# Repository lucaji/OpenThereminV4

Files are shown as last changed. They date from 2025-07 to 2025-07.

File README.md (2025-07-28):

# OpenTheremin v4.x platformio IDE

a new fork for the open source Theremin instrument software and hardware project by [GaudiLabs](https://github.com/GaudiLabs/OpenThereminV4). Adapted for [platformio](https://platformio.org/) IDE. Schematics, printed circuit board (PCB) design, bill of materials (BOM) and Arduino UNO compatible software for the OpenTheremin v4.x

> This repository brings an refactored, cleaned, fully commented and slightly optimized firmware for all OpenTheremin v4.x boards.

Lots of experimentation with this firmware is possible, check `build.h` for options.

## Waveform interpolation

Three waveform interpolation algorithms are included for experimenting with the 328p DDS generation:

- NONE (LEGACY)
- LINEAR
- HERMITE
- CATMULL-ROM (pushing the limits of the 328p - computational hungry!)

There is an interactive mode where each mode can be selected by muting/unmuting the Theremin. Using the NONE (LEGACY) mode, gives anyway a clean spectrum content on the audio output, fast responsiveness and an extended pitch range because of the optimizations that were already in place in the original OpenTheremin firmware.

## Serial port configuration

- Off (saves resources!)
- DEBUG (gives some state information)
- MIDI (emits MIDI data at 31250bps)

## Open Source Theremin based on the Arduino Platform

OpenTheremin is an arduino based real Theremin instrument. The legendary music instrument was invented by [Leon Theremin](https://www.google.com/url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) back in 1920.

The Theremin is played with both hands around two antennas, one to control the pitch and the other for volume expressivity.

The fully assembled version 4.x of OpenTheremin leverages two heterodyne VCO oscillators (voltage controlled) to measure the distance of the hands to each antenna while playing the instrument, by comparing those frequencies with two fixed frequency local oscillators.

The resulting signals (beating) are fed to and processed by a AtMega328P microcontroller which applies linearization and filtering in real-time, generating the sound reflecting the player's hands movements in the thin air.

There is an fast audio DAC onboard which delivers high quality digital audio, generated via a DDS (Direct Digital Synthesis) synth accessing serveral user-presettable and customizable wavetables to achieve different timbres.

## Instructions

This repo favours [VSCode + Platformio IDE](https://platformio.org/install/ide?install=vscode) as development environment instead of the Arduino IDE, still retaining compatibility though.

To fully enjoy a better development experience, it is advised to install Visual Studio Code and add the platformio IDE plug-in. After the latter has been installed, just opening the folder in VS Code will activate the platformio IDE.

## Ordering preassembled and tested boards

For more info on the open source project and on availability of ready made shield see:

https://www.gaudi.ch/OpenTheremin/

## Limits

> please be aware that the included DDS sound generator algorithm on a 16MHz 328p (Arduino UNO compatible) which is hardware driven by a two etherodyne RF VCO (voltage controlled oscillators) is already pushing the limits of the internal timers and interrupt pressure.

The lesser additional options you include in the build, the better sound quality:

- keep the serial port disabled if you don't need it.
- disable the CV/GATE outputs if you don't need them.
- select the desired interpolation mode if you like one - OFF otherwise!

#### LAST REVISION:

July 2025 by Luca Cipressi (lucaji.github.io)

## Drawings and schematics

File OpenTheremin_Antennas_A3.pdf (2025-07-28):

# VOLUME ANTENNA

# Theremin Volume Connector

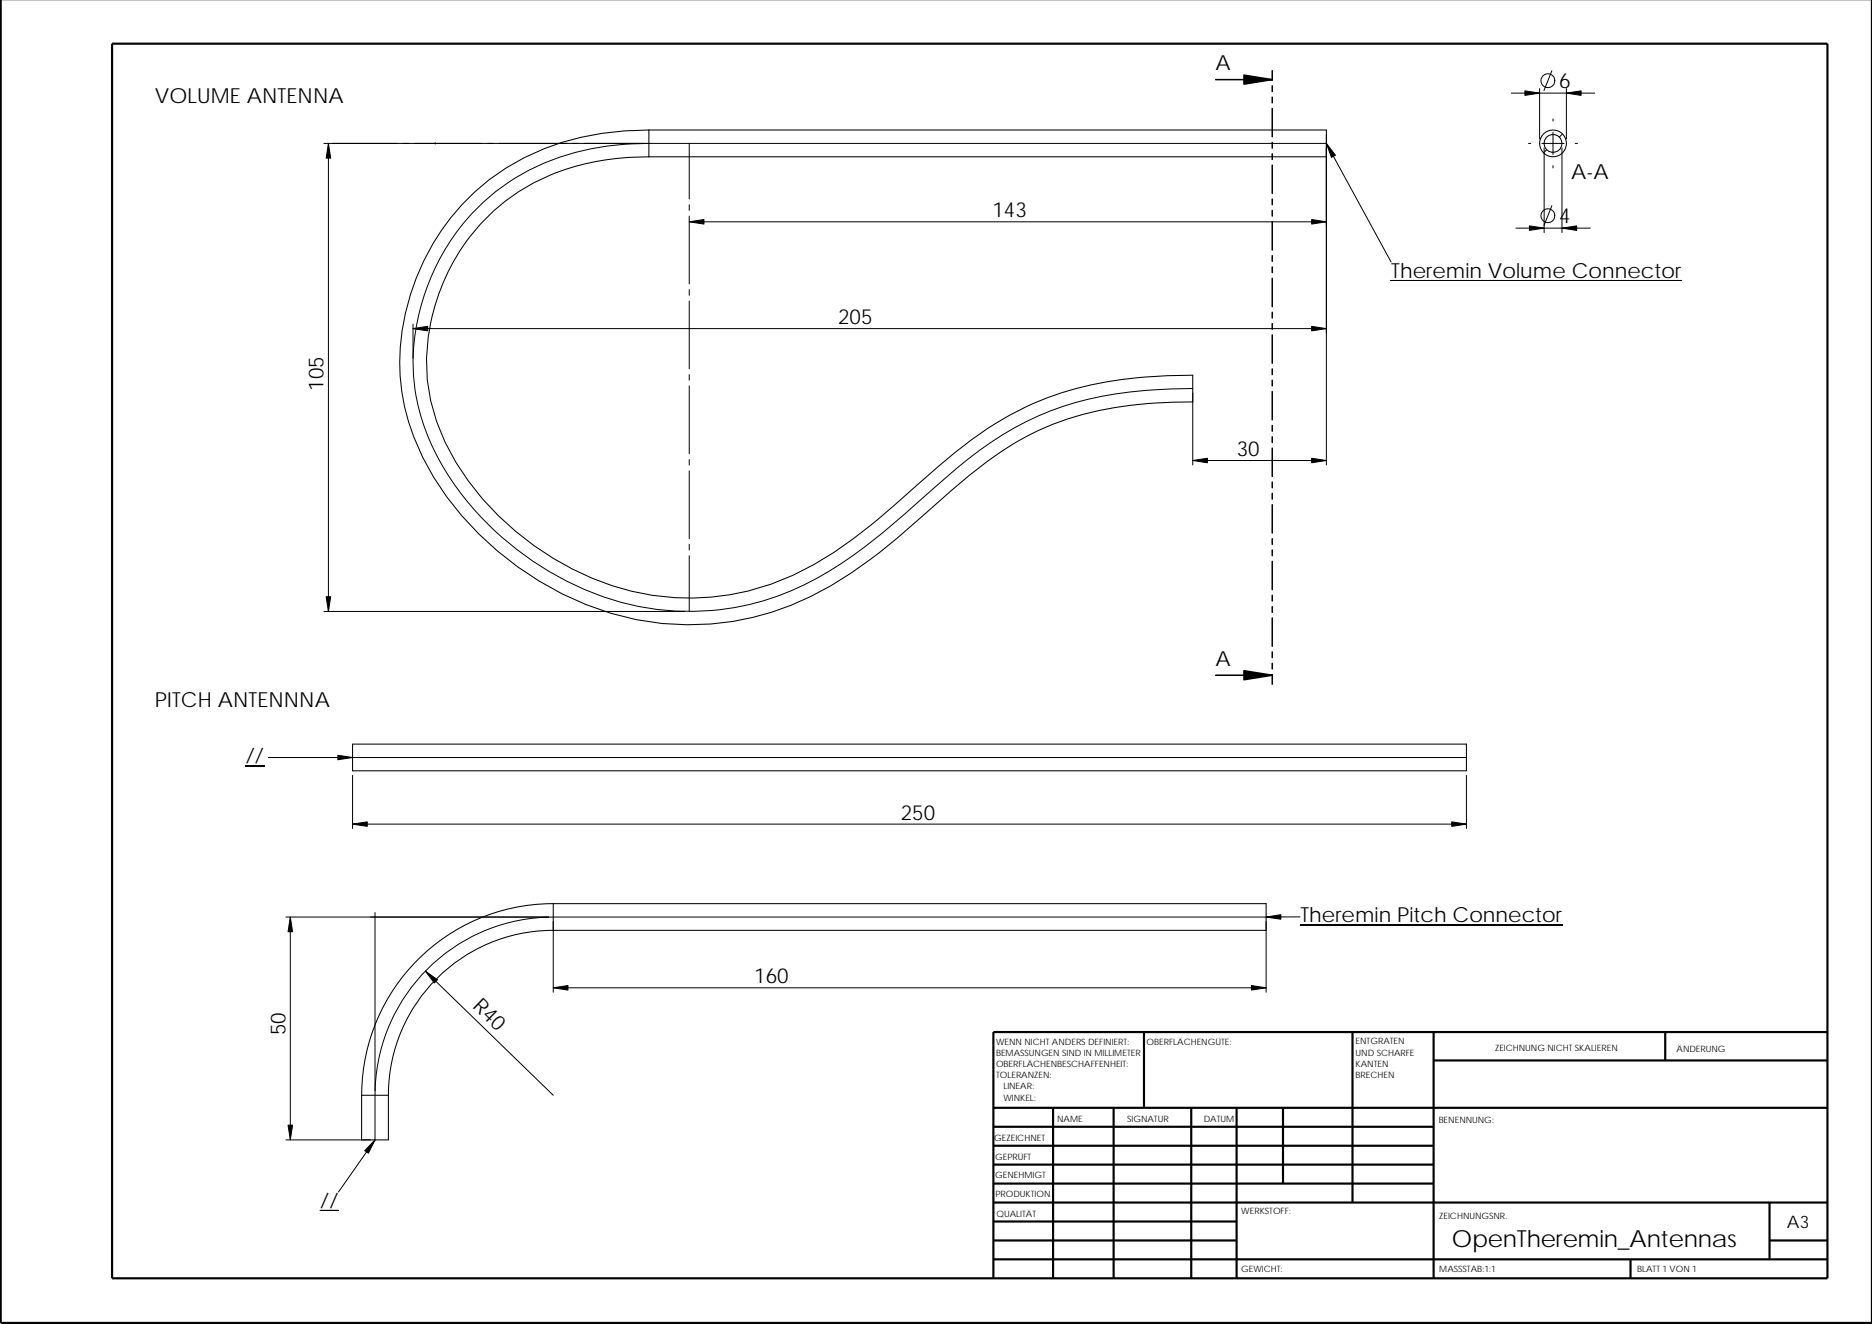
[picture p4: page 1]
PITCH ANTENNNA; GEWICHT:; MASSSTAB:1:1; BLATT 1 VON 1; ZEICHNUNG NICHT SKALIEREN; ÄNDERUNG; OBERFLÄCHENGÜTE:; ENTGRATEN; KANTEN BRECHEN; UND SCHARFE

Theremin Pitch Connector

WENN NICHT ANDERS DEFINIERT:
BEMASSUNGEN SIND IN MILLIMETER
OBERFLÄCHENBESCHAFFENHEIT:
TOLERANZEN:
LINEAR:
WINKEL:

NAME | SIGNATUR | DATUM | | | | BENENNUNG:

GEZEICHNET
GEPRÜFT
GENEHMIGT
PRODUKTION
QUALITÄT | | | | WERKSTOFF: | ZEICHNUNGSNR. OpenTheremin_Antennas | A3

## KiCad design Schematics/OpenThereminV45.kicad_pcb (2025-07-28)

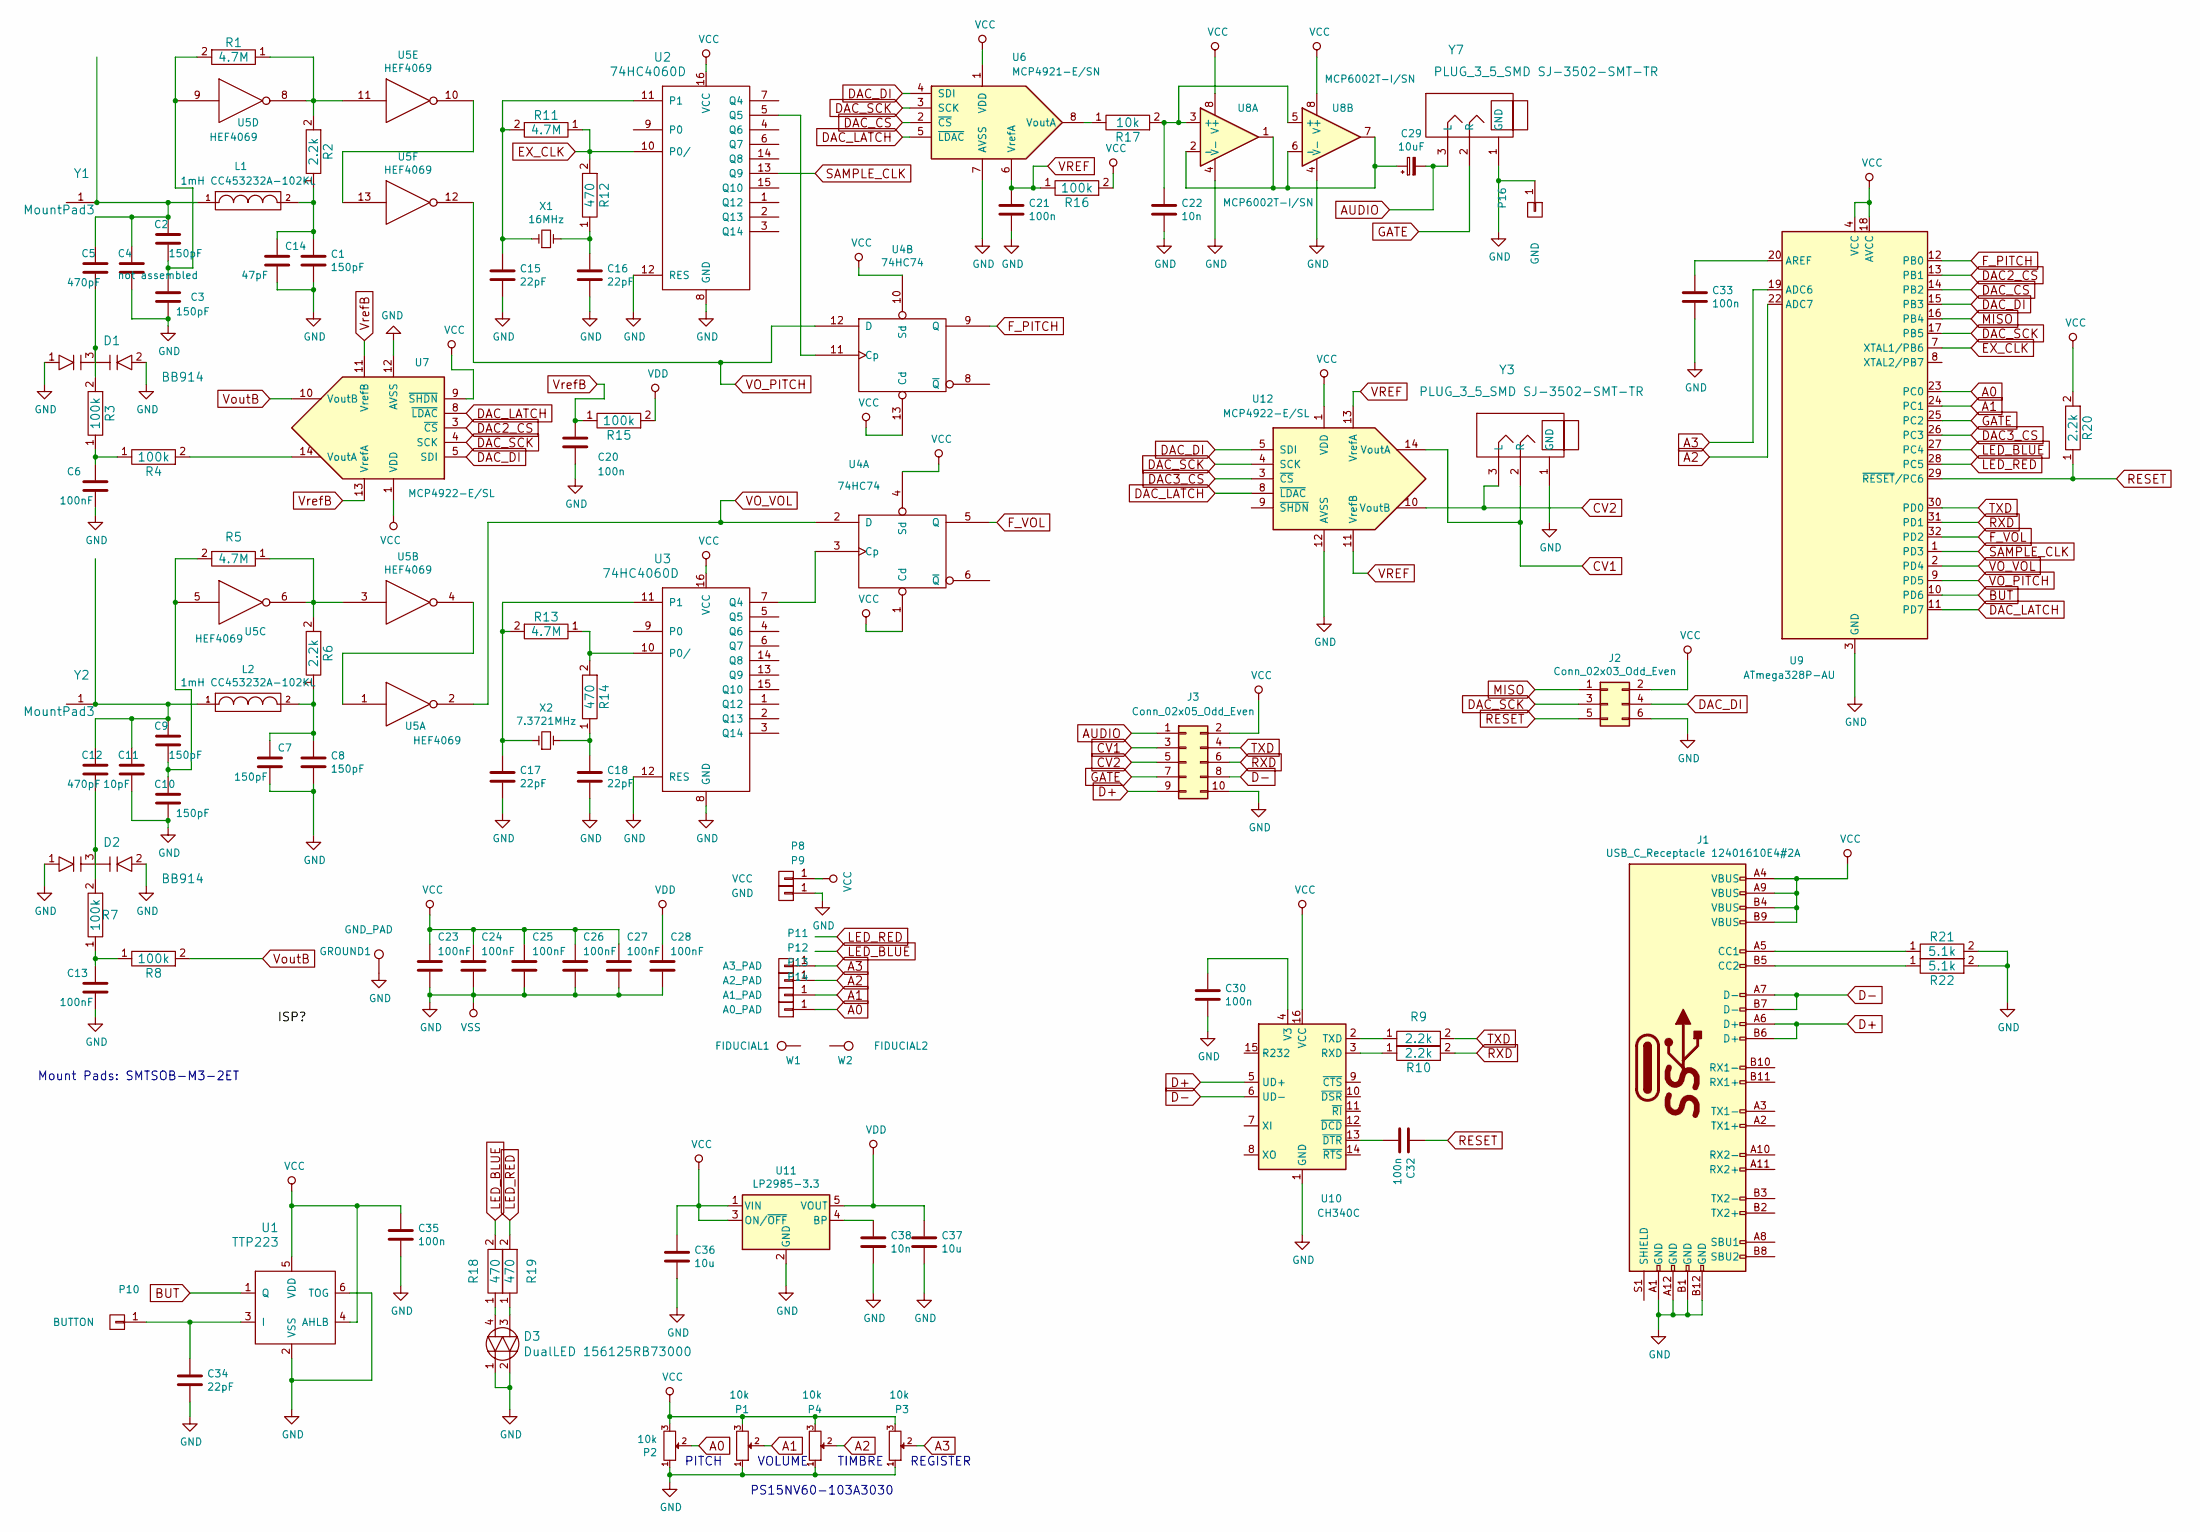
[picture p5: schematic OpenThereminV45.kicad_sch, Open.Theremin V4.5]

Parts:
C1, C2, C3, C7, C8, C9, C10: 150pF; C_0603_1608Metric
C4: not assembled; C_0603_1608Metric
C5, C12: 470pF; C_0603_1608Metric
C6, C13, C23, C24, C25, C26, C27, C28: 100nF; C_0603_1608Metric
C11: 10pF; C_0603_1608Metric
C14: 47pF; C_0603_1608Metric
C15, C16, C17, C18, C34: 22pF; C_0603_1608Metric
C20, C21, C30, C32, C33, C35: 100n; C_0603_1608Metric
C22, C38: 10n; C_0603_1608Metric
C29: 10uF; C_0603_1608Metric
C36, C37: 10u; C_0603_1608Metric
D1, D2: BB914; SOT-23
D3: DualLED 156125RB73000; WL-SBRW
GROUND1: GND_PAD; GNDPad
J1: USB_C_Receptacle 12401610E4#2A; USB_C_Receptacle_Amphenol_12401610E4-2A
J2: Conn_02x03_Odd_Even; Tag-Connect_TC2030-IDC-NL_2x03_P1.27mm_Vertical
J3: Conn_02x05_Odd_Even; PinHeader_2x05_P1.27mm_Vertical_SMD
L1, L2: 1mH CC453232A-102KL; COIL_T
P1, P2, P3, P4: 10k; PS15NV60
P8: VCC; SMD_Pinheader_1_OT_BLANK
P9, P16: GND; SMD_Pinheader_1_OT_BLANK
P10: BUTTON; SensorButton
P11: A3_PAD; SMD_Pinheader_1_OT_BLANK
P12: A2_PAD; SMD_Pinheader_1_OT_BLANK
P13: A1_PAD; SMD_Pinheader_1_OT_BLANK
P14: A0_PAD; SMD_Pinheader_1_OT_BLANK
R1, R5, R11, R13: 4.7M; R_0603_1608Metric
R2, R6, R9, R10, R20: 2.2k; R_0603_1608Metric
R3, R4, R7, R8, R15, R16: 100k; R_0603_1608Metric
R12, R14, R18, R19: 470; R_0603_1608Metric
R17: 10k; R_0603_1608Metric
R21, R22: 5.1k; R_0603_1608Metric
U1: TTP223; SOT-23-6
U2, U3: 74HC4060D; SOIC-16_3.9x9.9mm_P1.27mm
U4: 74HC74; SOIC-14_3.9x8.7mm_P1.27mm
U5: HEF4069; SOIC-14_3.9x8.7mm_P1.27mm
U6: MCP4921-E/SN; SOIC-8_3.9x4.9mm_P1.27mm
U7, U12: MCP4922-E/SL; SOIC-14_3.9x8.7mm_P1.27mm
U8: MCP6002T-I/SN; SOIC-8_3.9x4.9mm_P1.27mm
U9: ATmega328P-AU; TQFP-32_7x7mm_P0.8mm
U10: CH340C; SOIC-16_3.9x9.9mm_P1.27mm
U11: LP2985-3.3; SOT-23-5
W1: FIDUCIAL1; Fiducial_1mm_Dia_2.54mm_Outer_CopperBottom
W2: FIDUCIAL2; Fiducial_1mm_Dia_2.54mm_Outer_CopperBottom
X1: 16MHz; Crystal_SMD_HC49-SD
X2: 7.3721MHz; Crystal_SMD_HC49-SD
Y1, Y2: MountPad3; SMTSOB_M3
Y3, Y7: PLUG_3_5_SMD SJ-3502-SMT-TR; SJ-3502-SMT-TR

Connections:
A0: P2.2, P14.1, U9.23 (PC0)
A1: P1.2, P13.1, U9.24 (PC1)
A2: P4.2, P12.1, U9.22 (ADC7)
A3: P3.2, P11.1, U9.19 (ADC6)
AUDIO: C29.2, J3.1, Y7.3 (L)
BUT: U1.1 (Q), U9.10 (PD6)
CV1: J3.3, U12.14 (VoutA), Y3.2 (R)
CV2: J3.5, U12.10 (VoutB), Y3.3 (L)
D+: J1.A6 (D+), J1.B6 (D+), J3.9, U10.5 (UD+)
D-: J1.A7 (D-), J1.B7 (D-), J3.8, U10.6 (UD-)
DAC2_CS: U7.3 (~CS), U9.13 (PB1)
DAC3_CS: U9.26 (PC3), U12.3 (~CS)
DAC_CS: U6.2 (~CS), U9.14 (PB2)
DAC_DI: J2.4, U6.4 (SDI), U7.5 (SDI), U9.15 (PB3), U12.5 (SDI)
DAC_LATCH: U6.5 (~LDAC), U7.8 (~LDAC), U9.11 (PD7), U12.8 (~LDAC)
DAC_SCK: J2.3, U6.3 (SCK), U7.4 (SCK), U9.17 (PB5), U12.4 (SCK)
EX_CLK: R11.1, R12.2, U2.10 (P0/), U9.7 (XTAL1/PB6)
F_PITCH: U4.9 (Q), U9.12 (PB0)
F_VOL: U4.5 (Q), U9.32 (PD2)
GATE: J3.7, U9.25 (PC2), Y7.2 (R)
GND: C1.2, C3.2, C4.2, C6.2, C7.2, C8.2, C10.2, C11.2, C13.2, C14.2, C15.2, C16.2, C17.2, C18.2, C20.2, C21.2, C22.2, C23.2, C24.2, C25.2, C26.2, C27.2, C28.2, C30.2, C33.2, C34.2, C35.2, C36.2, C37.2, C38.2, D1.1, D1.2, D2.1, D2.2, D3.1, D3.2, GROUND1.1, J1.A1 (GND), J1.A12 (GND), J1.B1 (GND), J1.B12 (GND), J2.6, J3.10, P1.1, P2.1, P3.1, P4.1, P9.1, P16.1, R21.2, R22.2, U1.2 (VSS), U1.6 (TOG), U2.8 (GND), U2.12 (RES), U3.8 (GND), U3.12 (RES), U4.7 (GND), U5.7 (VSS), U6.7 (AVSS), U7.12 (AVSS), U8.4 (V-), U9.3 (GND), U9.5 (GND), U9.21 (GND), U10.1 (GND), U11.2 (GND), U12.12 (AVSS), Y3.1 (GND), Y7.1 (GND)
LED_BLUE: R18.2, U9.27 (PC4)
LED_RED: R19.2, U9.28 (PC5)
MISO: J2.1, U9.16 (PB4)
unnamed: C1.1, C14.1, L1.2, R2.1
unnamed: C2.1, C4.1, C5.1, L1.1, Y1.1
unnamed: C5.2, D1.3, R3.2
unnamed: C6.1, R3.1, R4.1
unnamed: C7.1, C8.1, L2.2, R6.1
unnamed: C9.2, C10.1, R5.2, U5.5
unnamed: C9.1, C11.1, C12.1, L2.1, Y2.1
unnamed: C12.2, D2.3, R7.2
unnamed: C13.1, R7.1, R8.1
unnamed: C15.1, R11.2, U2.11 (P1), X1.1
unnamed: C16.1, R12.1, X1.2
unnamed: C17.1, R13.2, U3.11 (P1), X2.1
unnamed: C18.1, R14.1, X2.2
unnamed: C22.1, R17.2, U8.3 (+), U8.5 (+)
unnamed: C29.1, U8.1, U8.2 (-), U8.6 (-), U8.7
unnamed: C30.1, U10.4 (V3)
unnamed: C32.2, U10.13 (~DTR)
unnamed: C33.1, U9.20 (AREF)
unnamed: C34.1, P10.1, U1.3 (I)
unnamed: C38.1, U11.4 (BP)
unnamed: D3.3, R19.1
unnamed: D3.4, R18.1
unnamed: J1.A5 (CC1), R21.1
unnamed: J1.B5 (CC2), R22.1
unnamed: R1.1, R2.2, U5.8, U5.11
unnamed: C2.2, C3.1, R1.2, U5.9
unnamed: R4.2, U7.14 (VoutA)
unnamed: R5.1, R6.2, U5.3, U5.6
unnamed: R9.1, U10.2 (TXD)
unnamed: R10.1, U10.3 (RXD)
unnamed: R13.1, R14.2, U3.10 (P0/)
unnamed: R17.1, U6.8 (VoutA)
unnamed: U2.5 (Q5), U4.11 (Cp)
unnamed: U3.7 (Q4), U4.3 (Cp)
unnamed: U5.1, U5.4
unnamed: U5.10, U5.13
RESET: C32.1, J2.5, R20.1, U9.29 (~RESET/PC6)
RXD: J3.6, R10.2, U9.31 (PD1)
SAMPLE_CLK: U2.13 (Q9), U9.1 (PD3)
TXD: J3.4, R9.2, U9.30 (PD0)
VCC: C23.1, C24.1, C25.1, C26.1, C27.1, C35.1, C36.1, J1.A4 (VBUS), J1.A9 (VBUS), J1.B4 (VBUS), J1.B9 (VBUS), J2.2, J3.2, P1.3, P2.3, P3.3, P4.3, P8.1, R16.2, R20.2, U1.4 (AHLB), U1.5 (VDD), U2.16 (VCC), U3.16 (VCC), U4.1 (Cd), U4.4 (Sd), U4.10 (Sd), U4.13 (Cd), U4.14 (VCC), U6.1 (VDD), U7.1 (VDD), U7.9 (~SHDN), U8.8 (V+), U9.4 (VCC), U9.6 (VCC), U9.18 (AVCC), U10.16 (VCC), U11.1 (VIN), U11.3 (ON/~OFF), U12.1 (VDD)
VDD: C28.1, C37.1, R15.2, U5.14 (VDD), U11.5 (VOUT)
VO_PITCH: U4.12 (D), U5.12, U9.9 (PD5)
VO_VOL: U4.2 (D), U5.2, U9.2 (PD4)
VREF: C21.1, R16.1, U6.6 (VrefA), U12.11 (VrefB), U12.13 (VrefA)
VoutB: R8.2, U7.10 (VoutB)
VrefB: C20.1, R15.1, U7.11 (VrefB), U7.13 (VrefA)

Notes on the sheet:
REGISTER
VOLUME
TIMBRE
PITCH
PS15NV60-103A3030
Mount Pads: SMTSOB-M3-2ET

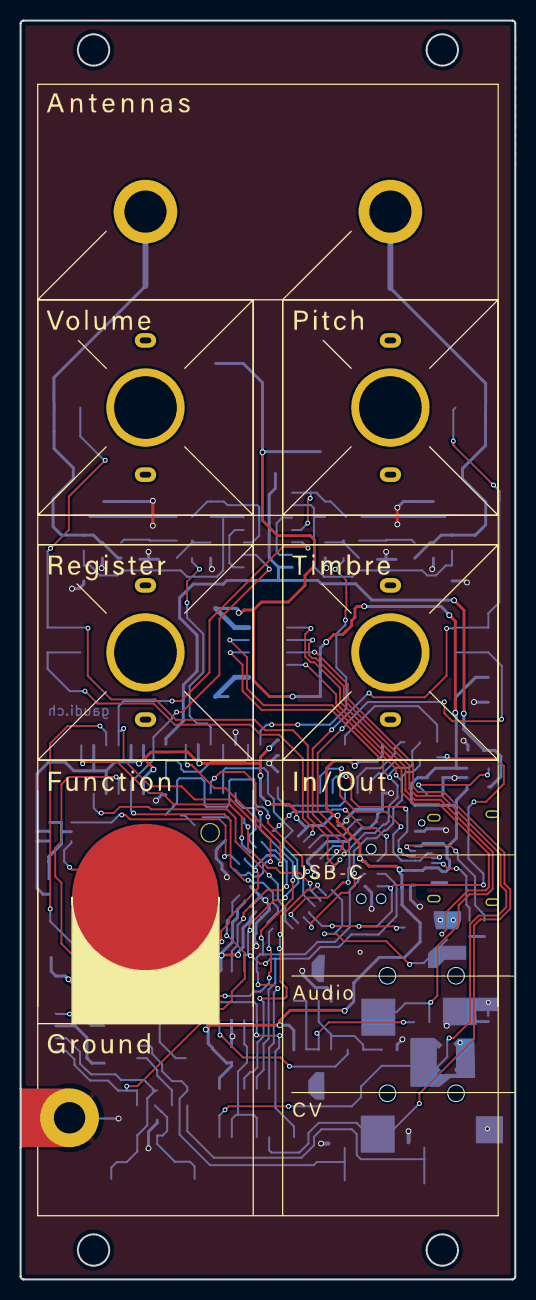
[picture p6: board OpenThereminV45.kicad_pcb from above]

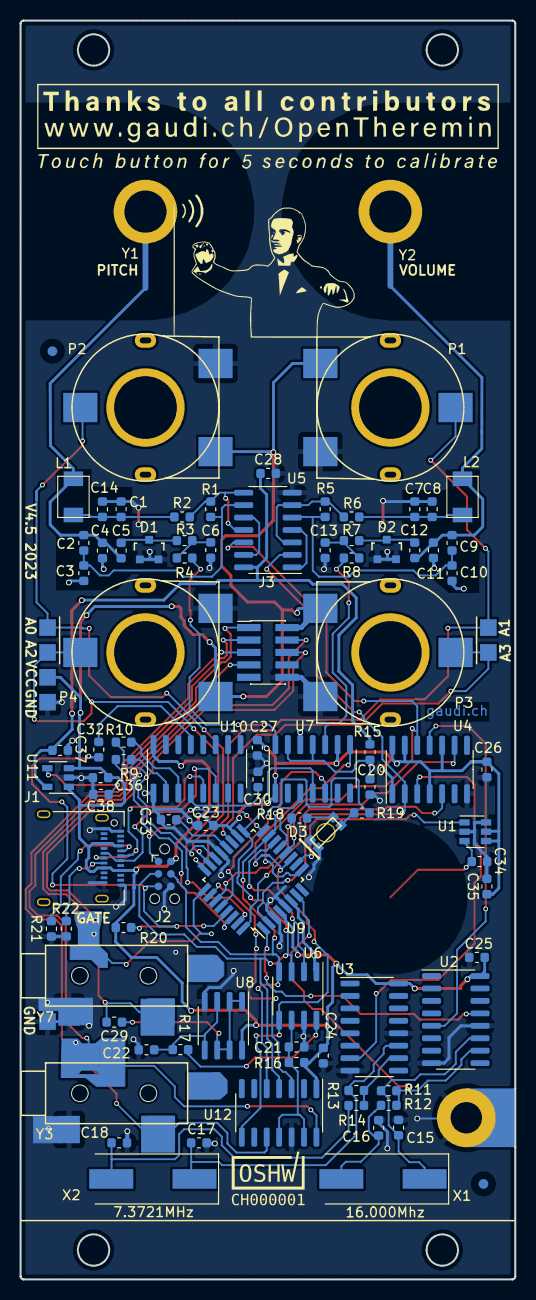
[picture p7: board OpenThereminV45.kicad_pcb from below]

Board: 2 copper layers, 50.5 x 128.5 mm, 99 parts (95 on the bottom side), 71 nets.

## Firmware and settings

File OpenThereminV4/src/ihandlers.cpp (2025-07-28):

#include "ihandlers.h"
#include "SPImcpDAC.h"
#include "timer.h"
#include "build.h"

#include "wavetable_0.h"
#include "wavetable_1.h"
#include "wavetable_2.h"
#include "wavetable_3.h"
#include "wavetable_4.h"
#include "wavetable_5.h"
#include "wavetable_6.h"
#include "wavetable_7.h"

#ifdef WAVEFORM_INCLUDE_PURE_SINE
#include "wavetable_pure_sine1024.h"
#endif

// future expansion from 1024 to 2048 point wavetables
#define DDS_WAVETABLE_RESOLUTION 0x3ff
const int16_t *const wavetables[] = {
    #ifdef WAVEFORM_INCLUDE_PURE_SINE
        wavetable_sine1024, // pure sine
    #endif
        wavetable_0,
        wavetable_1,
        wavetable_2,
        wavetable_3,
        wavetable_4,
        wavetable_5,
        wavetable_6,
        wavetable_7,
};
const uint8_t num_wavetables = (sizeof(wavetables) / sizeof(wavetables[0]));

#if INTERPOLATION_MODE == INTERPOLATION_MODE_INTERACTIVE
volatile uint8_t interpolation_mode = 0;        // accessible from main loop
#endif

static const uint32_t MCP_DAC_BASE = 2048;

#define F_VOL_PIN (PIND & (1 << PORTD2))
#define F_PITCH_PIN (PINB & (1 << PORTB0))

volatile uint16_t vScaledVolume = 0;        // output level amplitude
volatile uint16_t vPointerIncrement = 0;    // phase accumulator increment

volatile uint16_t pitch = 0;                // Pitch value
volatile uint16_t pitch_counter = 0;        // Pitch counter
volatile uint16_t pitch_counter_l = 0;      // Last value of pitch counter

volatile bool volumeValueAvailable = 0;     // Volume read flag
volatile bool pitchValueAvailable = 0;      // Pitch read flag
volatile bool reenableInt1 = 0;             // reeanble Int1

volatile uint16_t vol;                      // Volume value
volatile uint16_t vol_counter = 0;          // volume counter
volatile uint16_t vol_counter_i = 0;        // Volume counter Timer 1
volatile uint16_t vol_counter_l;            // Last value of volume counter

volatile int16_t pitchCV;                   // Pitch CV value
volatile uint16_t volCV;                    // Volume CV value
volatile bool volumeCVAvailable;            // Volume CV flag
volatile bool pitchCVAvailable;             // Pitch CV flag

volatile uint16_t timer_overflow_counter;   // counter for frequency measurement
volatile uint8_t vWavetableSelector = 0;    // wavetable selector

static volatile uint16_t pointer = 0;       // Table pointer 22-bit: 16 bits integer + 6 bits fraction

#if DDS_DEBOUNCE_MODE == DDS_DEBOUNCE_MODE_LEGACY
static volatile uint8_t debounce_p, debounce_v = 0; // Counters for debouncing
#endif

/**
 * @brief Initializes hardware timers used for pitch frequency measurement and system timing.
 *
 * This function sets up:
 * - Timer1 in normal mode with input capture on rising edge at full 16 MHz clock rate,
 *     used to measure the frequency of the pitch oscillator via the ICP1 pin (PD5 / Digital 5).
 * - Timer0 with Arduino default Fast PWM mode and a 64× prescaler,
 *     which supports core timing functions like `millis()` and `delay()`.
 *
 * Timer1 Input Capture Interrupt is enabled to allow precise measurement of pitch events.
 * Timer0 Overflow Interrupt is also enabled, following Arduino's default timer configuration.
 *
 * @note
 * - Timer1 is configured to run without prescaling for maximum frequency resolution.
 * - The ICES1 bit ensures rising edge detection on ICP1 (PD5).
 * - No waveform output is enabled; timers are used strictly for counting.
 */
void ihInitialiseTimer() {
    // --- Timer1: Pitch frequency measurement (ICP1 on PD5) ---        
    /**
     * TCCR1A controls waveform generation mode and output compare behavior.
     * Setting it to 0 disables waveform output on OC1A/OC1B and enables normal counting mode.
     */
    TCCR1A = 0; ///< Normal mode, no PWM output
    
    /**
     * TCCR1B:
     * - ICES1: Input Capture Edge Select → 1 = capture on rising edge
     * - CS10:    Clock Select → 1 = no prescaler (Timer1 counts at full 16 MHz)
     */
    TCCR1B = (1 << ICES1) | (1 << CS10); ///< Rising edge capture, no prescaling

    /**
     * TIMSK1:
     * - ICIE1: Enable Timer1 Input Capture interrupt (TIMER1_CAPT_vect)
     */
    TIMSK1 = (1 << ICIE1); ///< Enable input capture interrupt

    // --- Timer0: Arduino core timebase (used by millis/delay) ---

    /**
     * TCCR0A:
     * - WGM01 + WGM00 = 1 → Fast PWM mode (Arduino default)
     */
    TCCR0A = 0x03; ///< Fast PWM mode

    /**
     * TCCR0B:
     * - CS01 + CS00 = 1 → Prescaler = clk/64 (Timer0 runs at 250 kHz)
     */
    TCCR0B = 0x03; ///< Clock /64 prescaler

    /**
     * TIMSK0:
     * - TOIE0: Enable Timer0 Overflow Interrupt (used by Arduino core)
     */
    TIMSK0 = 0x01; ///< Enable Timer0 overflow interrupt
}

/**
 * @brief Configures external interrupts for wave generator and volume measurement.
 *
 * This function sets up the External Interrupt Control Register (EICRA) to trigger interrupts
 * on rising edges for both INT0 (volume gate, F_VOL) and INT1 (sample clock / wave generator tick).
 * These are connected respectively to PD2 (INT0) and PD3 (INT1) on the ATmega328P.
 *
 * - INT0 is used to latch volume oscillator timing information from the flip-flop gate.
 * - INT1 triggers the main waveform ISR for audio output and pitch/volume tracking.
 *
 * External interrupts are enabled in the mask register (EIMSK), and a software flag
 * (`reenableInt1`) is set to allow re-arming INT1 from within the ISR after it's temporarily disabled.
 *
 * @note This setup is AVR-specific. On ARM MCUs like the DUE or STM32, similar behavior
 *             would be implemented with attachInterrupt() or direct NVIC/GPIO interrupt configuration.
 */
void ihInitialiseInterrupts() {
    // --- Configure interrupt trigger type for INT0 (PD2) and INT1 (PD3) ---

    /* EICRA – External Interrupt Control Register A
            ISC00 + ISC01 = 1 + 1 = Rising edge trigger for INT0 (Volume)
            ISC10 + ISC11 = 1 + 1 = Rising edge trigger for INT1 (Wave ISR)
    */
    EICRA = (1 << ISC00) | (1 << ISC01) | (1 << ISC11) | (1 << ISC10);

    reenableInt1 = true; // Internal flag to allow INT1 to be re-enabled in the main ISR

    /* EIMSK – External Interrupt Mask Register
            Enables INT0 (bit 0) and INT1 (bit 1)
    */
    EIMSK = (1 << INT0) | (1 << INT1);
}
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

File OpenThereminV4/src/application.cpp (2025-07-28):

#include "application.h"
#include "SPImcpDAC.h"
#include "ihandlers.h"
#include "timer.h"
#include "EEPROM.h"

#define BUTTON_PIN 6
#define HW_BUTTON_STATE         (PIND & (1<<PORTD6))
#define HW_BUTTON_PRESSED       (HW_BUTTON_STATE == LOW)
#define HW_BUTTON_RELEASED      (HW_BUTTON_STATE != LOW)

#define LED_BLUE_PIN 18
#define HW_LED_BLUE_ON          (PORTC |= (1<<PORTC4))
#define HW_LED_BLUE_OFF         (PORTC &= ~(1<<PORTC4))
#define HW_LED_BLUE_TOGGLE      (PORTC = PORTC ^ (1<<PORTC4))

#define LED_RED_PIN 19
#define HW_LED_RED_ON           (PORTC |= (1<<PORTC5))
#define HW_LED_RED_OFF          (PORTC &= ~(1<<PORTC5))
#define HW_LED_RED_TOGGLE       (PORTC = PORTC ^ (1<<PORTC5))

#define GATE_PULLUP             (DDRC &= ~(1<<PORTC2)); (PORTC |= (1<<PORTC2))
#define GATE_SENSE              (PINC & (1<<PORTC2))
#define GATE_DRIVE_HIGH         (DDRC |= (1<<PORTC2))
#define GATE_DRIVE_LOW          (PORTC &= ~(1<<PORTC2)); (DDRC |= (1<<PORTC2))

#define PITCH_POT 0
#define VOLUME_POT 1
#define WAVE_SELECT_POT 7
#define REGISTER_SELECT_POT 6
#define HYST_SCALE 0.7  // between 0.3 and 0.7 usually
static const int16_t pot_register_selection_hysteresis = 1024.0 / 3 * HYST_SCALE;
static const int16_t pot_waveform_selection_hysteresis = 1024.0 / num_wavetables * HYST_SCALE;

#define MAX_VOLUME 4095         // 12 bit DAC max clamping value

static int16_t pitchDAC = 0;
static int16_t volumeDAC = 0;

static int32_t pitchCalibrationBase = 0;
static int32_t volCalibrationBase = 0;
const int16_t CalibrationTolerance = 15;
const int16_t PitchFreqOffset = 700;
const int16_t VolumeFreqOffset = 700;

#define FREQ_FACTOR 16000000U
#define PITCH_VO_TARGET_FREQUENCY  500000
#define VOLUME_VO_TARGET_FREQUENCY 460800
static float qMeasurement = 0;


Application::Application() {};

void Application::setup() {
    #if SERIAL_MODE == SERIAL_MODE_DEBUG
                Serial.begin(57600);
        #elif SERIAL_MODE == SERIAL_MODE_MIDI
                Serial.begin(31250);
        #endif

    pinMode(BUTTON_PIN, INPUT_PULLUP);
    pinMode(LED_BLUE_PIN, OUTPUT);
    pinMode(LED_RED_PIN, OUTPUT);

    HW_LED_RED_ON; HW_LED_BLUE_OFF; // standby mode

    SPImcpDACinit();
    EEPROM.get(0, pitchDAC);
    EEPROM.get(2, volumeDAC);

    SPImcpDAC2Asend(pitchDAC);
    SPImcpDAC2Bsend(volumeDAC);

    ihInitialiseTimer();
    ihInitialiseInterrupts();

    EEPROM.get(4, pitchCalibrationBase);
    EEPROM.get(8, volCalibrationBase);

    DEBUG_PRINT("P_CAL=");DEBUG_PRINT(pitchCalibrationBase);
    DEBUG_PRINT(" V_CAL=");DEBUG_PRINTLN(volCalibrationBase);
    DEBUG_PRINTLN("Hello, Theremin world!");
}

void Application::loop() {
    int32_t pitch_v = 0, pitch_l = 0; // Last value of pitch    (for filtering)
    int32_t vol_v = 0, vol_l = 0;        // Last value of volume (for filtering and for tracking)

    uint16_t volumePotValue = 0;
    uint16_t pitchPotValue = 0;
    int registerPotValue, registerPotValueL = 0;
    int wavePotValue, wavePotValueL = 0;
    uint8_t registerValue = 2; // octave
    uint16_t tmpVolume;
    uint16_t tmpPitch;

mloop: // Main loop avoiding the GCC "optimization"

    pitchPotValue = analogRead(PITCH_POT);
    volumePotValue = analogRead(VOLUME_POT);
    registerPotValue = analogRead(REGISTER_SELECT_POT);
    wavePotValue = analogRead(WAVE_SELECT_POT);

    if ((registerPotValue - registerPotValueL) >= pot_register_selection_hysteresis ||
        (registerPotValueL - registerPotValue) >= pot_register_selection_hysteresis) { 
        registerPotValueL = registerPotValue;
        // register pot configuration:
        // Left = -1 octave, Center = +/- 0, Right = +1 octave
        if (registerPotValue > 681) {
            registerValue = 1;
            DEBUG_PRINT("REG=");DEBUG_PRINTLN(registerValue);
        } else if (registerPotValue < 342) {
            registerValue = 3;
            DEBUG_PRINT("REG=");DEBUG_PRINTLN(registerValue);
        } else {
            registerValue = 2;
            DEBUG_PRINT("REG=");DEBUG_PRINTLN(registerValue);
        }
    }

    if (((wavePotValue - wavePotValueL) >= pot_waveform_selection_hysteresis) ||
        ((wavePotValueL - wavePotValue) >= pot_waveform_selection_hysteresis)) {
        wavePotValueL = wavePotValue;
        // map 0–1023 to 0–(num_wavetables - 1)
        uint16_t scaled = ((uint32_t)wavePotValue * num_wavetables) / 1024;
        if (scaled >= num_wavetables) scaled = num_wavetables - 1;  // extra safety
        vWavetableSelector = scaled;
        DEBUG_PRINT("WAV=");DEBUG_PRINTLN(vWavetableSelector);
    }

    if (_state == PLAYING && HW_BUTTON_PRESSED) {
        resetTimer();
        _state = CALIBRATING;
        _mode = _mode == NORMAL ? MUTE : NORMAL;
        if (_mode == NORMAL) {
            HW_LED_BLUE_ON; HW_LED_RED_OFF;

            #if INTERPOLATION_MODE == INTERPOLATION_MODE_INTERACTIVE
                if (interpolation_mode == INTERPOLATION_CATMULL_ROM) { interpolation_mode = INTERPOLATION_NONE; }
                else { interpolation_mode++; }
                switch (interpolation_mode) {
                    case INTERPOLATION_NONE: DEBUG_PRINTLN("INT_NONE"); break;
                    case INTERPOLATION_LINEAR: DEBUG_PRINTLN("INT_LINEAR"); break;
                    case INTERPOLATION_HERMITE: DEBUG_PRINTLN("INT_HERMITE"); break;
                    case INTERPOLATION_CATMULL_ROM: DEBUG_PRINTLN("INT_CATMULL"); break;
                    default: DEBUG_PRINTLN("ERR INTERP MODE"); break;
                }
            #endif
        } else {
            HW_LED_BLUE_OFF; HW_LED_RED_ON;
        }
    }

    if (_state == CALIBRATING && HW_BUTTON_RELEASED) {
        _state = PLAYING;
    }

    if (_state == CALIBRATING && timerExpired(65000)) {
        HW_LED_BLUE_ON; HW_LED_RED_ON;

        #ifdef ENABLE_AUDIO_FEEDBACK
        playNote(MIDDLE_C, 150, 25);
        playNote(MIDDLE_C * 2, 150, 25);
        playNote(MIDDLE_C * 4, 150, 25);
        #endif

        bool success = calibrate_pitch();
        if (success) {
            success = calibrate_volume();
        }
        ihInitialiseTimer();
        ihInitialiseInterrupts();

        if (success) {
            calibrate();
            #ifdef ENABLE_AUDIO_FEEDBACK
            playNote(MIDDLE_C * 2, 150, 25);
            playNote(MIDDLE_C * 2, 150, 25);
            #endif
        } else {
            #ifdef ENABLE_AUDIO_FEEDBACK
            playNote(MIDDLE_C * 4, 150, 25);
            playNote(MIDDLE_C, 150, 25);
            #endif
        }

        _mode = NORMAL;
        HW_LED_RED_OFF;

        while (HW_BUTTON_PRESSED) {}
        _state = PLAYING;
    }

    if (pitchValueAvailable) {
        // Averaging pitch values
        pitch_p = pitch;
        pitch_v = pitch;
        pitch_v = pitch_l + ((pitch_v - pitch_l) >> 2); ///< (low-pass) exponential moving average (EMA) approximation
        pitch_l = pitch_v;
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

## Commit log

2025-07-28 cleaned, optimized, commented and expanded for experiments
    [OpenThereminCC-2019-06-01-18-08-36.sch, OpenThereminCC-2019-06-01-19-16-51.sch, OpenThereminCC-2019-06-01-20-19-36.sch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]
2025-08-11 expanded the build.h file with comments and cleaner options, cleaned the CV/GATE handling in main application, added serial debug macros instead of Serial.print statements
2025-08-11 added solid potentiometer reading logic with hysteresis check to minimize DDS impact, position now is correctly read at power-on too
    [application.cpp, ihandlers.cpp]
2025-08-12 new solid calibration algorithm (with success/fail indication) moved to separate translation unit. Removed Application class in favour of plain C methods (no need to instantiate more than one class -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
    [Open_Theremin_V4.ino, application.cpp, build.h]
2025-08-12 optimized DAC (ihandlers.cpp) by removing unnecessary interrupt blocking/unblocking calls - ISR has already highest prio. DAC code has now forced inlining and proper SPIF register clearing, removed u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
    [ihandlers.cpp]
